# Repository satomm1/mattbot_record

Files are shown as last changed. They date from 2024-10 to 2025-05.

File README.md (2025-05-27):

# Streaming Stereo Audio from I2S PCM Microphones to Nvidia Jetson Orin Nano

This repo contains code for streaming stereo audio from I2S PCM microphones to a Nvidia Jetson Orin Nano developer kit. In my case, I use a InvenSense ICS-43434 MEMS microphone. To convert the 24 bit PCM data output from the microphone to a form readable by the Jetson audio drivers, I use a PIC32MK0128MCA048T-I/Y8X microcontroller to convert the data to 32 bit and the correct endianness. 

Custom PCBs were designed to facilitate the MEMS microphones, PIC32, and connection to the Jetson. These PCBs were designed with KICAD and the designs (and KICAD files) are located in the `./pcb` directory. To order your own PCBs, the necessary gerber files are located in a `./pcb/*/gerber` directory. A BOM for each of the pcbs is also located in the directory (with part numbers for ordering from DigiKey).

The firmware for the PIC32 is located in the `./firmware` directory. This code should be loaded onto the PIC32 and supports sampling rates up to 44,100 Hz.

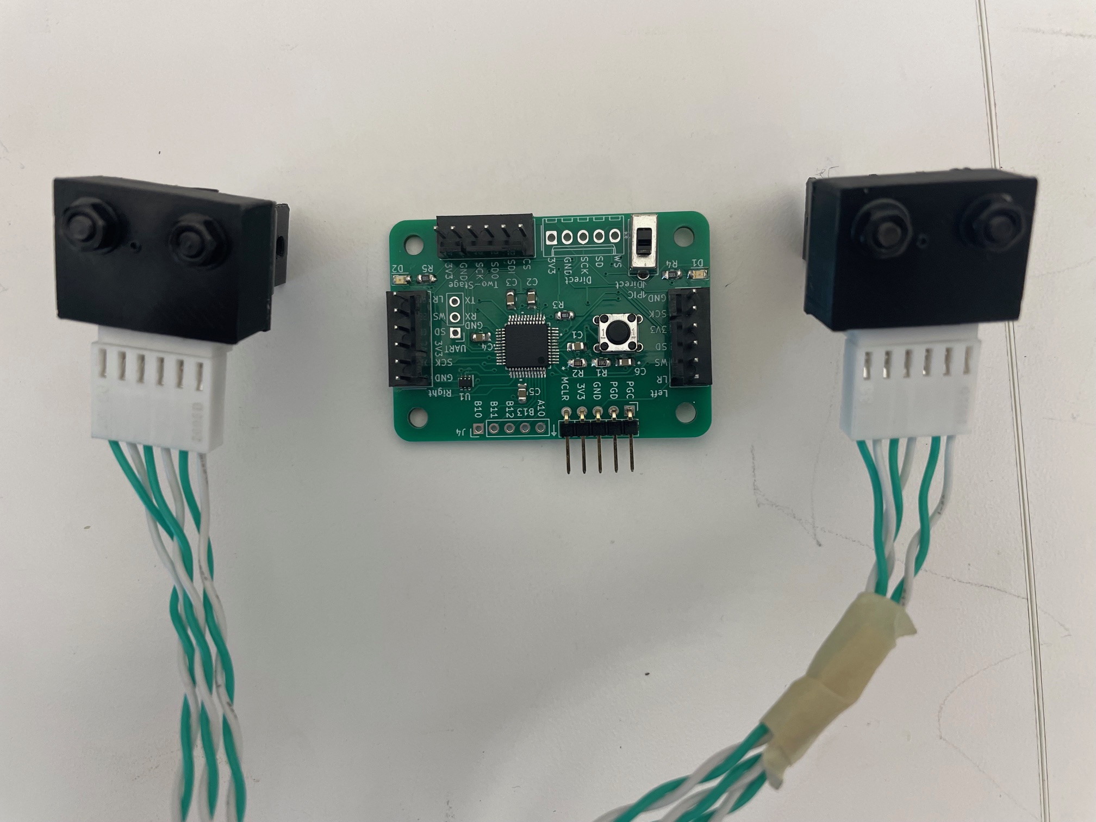
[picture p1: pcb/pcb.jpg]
PCB Design


I include STL/Solidworks files for mounts for the microphones in the `./mounts` directory. These can be 3D printed. For a gasket, you can use a foam double sided tape found at a hardware store. For an acoustically transparent fabric to protect the port, I used muslin which can be found at a fabric store.

To enable the I2S on the Jetson, enable the I2S functionality via:
```
sudo python3 /opt/nvidia/jetson-io/jetson-io.py
```
As a simple test to see if the audio is working, you can use these commands to save a recording to `output.wav`:
```
amixer -c APE cset name="ADMAIF2 Mux" I2S2
arecord -D hw:APE,1 -r 16000 -c 2 -f S32_LE output.wav
```
Note, you will need to run the `amixer` command regardless before I2S audio will be read by the Jetson. It may also be necessary to run `python3 ./scripts/channels.py` to determine which audio device to use for the above example. If you find you need to change from `hw:APE,1` to something else, you will need to modify the other python files as well.

To use the I2S on the Nvidia Jetson with Python, you need to make sure you have installed the following packages:
```
pip install pyalsaaudio
sudo apt-get install libasound2-dev
sudo apt-get install alsa-utils
```
To test the python audio, run:
```
python3 ./scripts/record.py
```
which will save a short 5 second recording to `./scripts/output.wav`. To see the sound in frequency domain, you can run `./scripts/analyze_wav.py`.

We use a wakeword to determine when to start listening. The opensource [openWakeWord](https://github.com/dscripka/openWakeWord) is used to identify "Hey Robot," but the openWakeWord repo describes how to easily create your own wakeword. We also use the opensource [Silero voice activity detector](https://github.com/snakers4/silero-vad) to identify when speech has ended. Speech which is recorded is transcribed using [Whisper](https://github.com/openai/whisper). Recently, the transcription has been changed to [Faster Whisper](https://github.com/SYSTRAN/faster-whisper), which uses less computational resources. These features require the installation of additional dependencies:
```
pip install openwakeword
pip install silero-vad
pip install -U openai-whisper
pip install faster-whisper
```

Note: As of 12/7/2024, there is issues with the python package tokenizer version 0.21.0 for faster-whisper. I recommend installing an earlier version.

You will also need to download model files for openWakeWord. You can do this with `openwakeword.utils.download_models()` in python, or you can just run `./scripts/wakeword.py` which will also download the necessary model files.

Putting all this together, we create a function which:
1) Initializes the I2S interface on the Jetson.
2) Records audio using the I2S interface.
3) Detects the wakeword using openWakeWord.
4) Records speech until silence is detected using Silero VAD.
5) Saves the recorded audio to a file.
6) Transcribes the audio.
7) (optional) Sends the transcription to an LLM for a response.
Try it out using:
```
python3 ./scripts/get_audio_wakeword_speech_detection.py
```
This repo is set up as a ROS package compatible with ROS Noetic.

## Launching the Microphones
The relevant launch file is `audio_with_speech_detection.launch` which can be run with:
```
roslaunch mattbot_record audio_with_speech_detection.launch
```

**Author**: Matthew Sato, Stanford Engineering Informatics Group

**License**: This package is released under an [MIT License](./LICENSE).

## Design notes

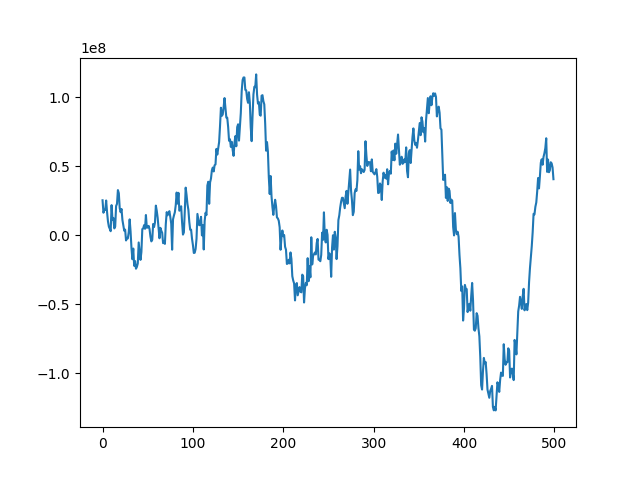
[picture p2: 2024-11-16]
scripts/audio_data.png

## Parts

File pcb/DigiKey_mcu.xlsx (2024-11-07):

References | Value | Mfr | Mfr P/N | Supplier 1 | Supplier 1 P/N | Quantity
C1, C2, C3, C4, C5, C6 | 0.1 uF | Samsung Electro-Mechanics | CL21B104KBCNNNC | DigiKey | 1276-1003-1-ND | 6
R4, R5 | 130R | Stackpole Electronics Inc | RMCF0805FT130R | DigiKey | RMCF0805FT130RCT-ND | 2
R1 | 10k | Stackpole Electronics Inc | RMCF0805JT10K0 | DigiKey | RMCF0805JT10K0CT-ND | 1
R2 | 1k | Stackpole Electronics Inc | RMCF0805FT1K00 | DigiKey | RMCF0805FT1K00CT-ND | 1
R3 | 100k | Stackpole Electronics Inc | RMCF0805FG100K | DigiKey | RMCF0805FG100KCT-ND | 1
D1, D2 | LED | Würth Elektronik | 150080RS75000 | DigiKey | 732-4984-1-ND | 2
U1 | GSF7002DW | Good-Ark Semiconductor | GSF7002DW | DigiKey | 4786-GSF7002DWCT-ND | 1
SW1 | B3F-1020 | Omron Electronics Inc-EMC Div | B3F-1020 | DigiKey | SW402-ND | 1
SW2 | SW_SPDT | C&K | OS102011MS2QN1 | DigiKey | CKN9565-ND | 1
IC1 | PIC32MK0128MCA048-I_Y8X | Microchip Technology | PIC32MK0128MCA048T-I/Y8X | DigiKey | 150-PIC32MK0128MCA048T-I/Y8XCT-ND | 1
J2, J3, J5 | Conn_01x06 | Molex | 1718560006 | DigiKey | WM10156-ND | 3
J6 | Conn_01x05 | Molex | 1718560005 | DigiKey | WM10183-ND | 1
J8 | Conn-Femalex6 | Molex | 22012067 | DigiKey | WM2015-ND | 3
J9 | Conn-Femalex5 | Molex | 22012057 | DigiKey | WM2014-ND | 1
J10 | Conn-Crimp | Molex | 8510108 | DigiKey | WM19393CT-ND | 8

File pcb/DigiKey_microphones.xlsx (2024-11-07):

References | Value | Mfr | Mfr P/N | Supplier 1 | Supplier 1 P/N | Quantity
C1 | 0.1 uF | Samsung Electro-Mechanics | CL21B104KBCNNNC | DigiKey | 1276-1003-1-ND | 1
MK1 | ICS-43434 | TDK InvenSense | ICS-43434 | DigiKey | 1428-1066-1-ND | 1
J1 | Conn2MCU | Molex | 22053061 | DigiKey | WM4304-ND | 1
J2 | Conn2MCU-Female | Molex | 22012067 | DigiKey | WM2015-ND | 1
J3 | Conn2MCU-Crimp | Molex | 8510108 | DigiKey | WM19393CT-ND | 2

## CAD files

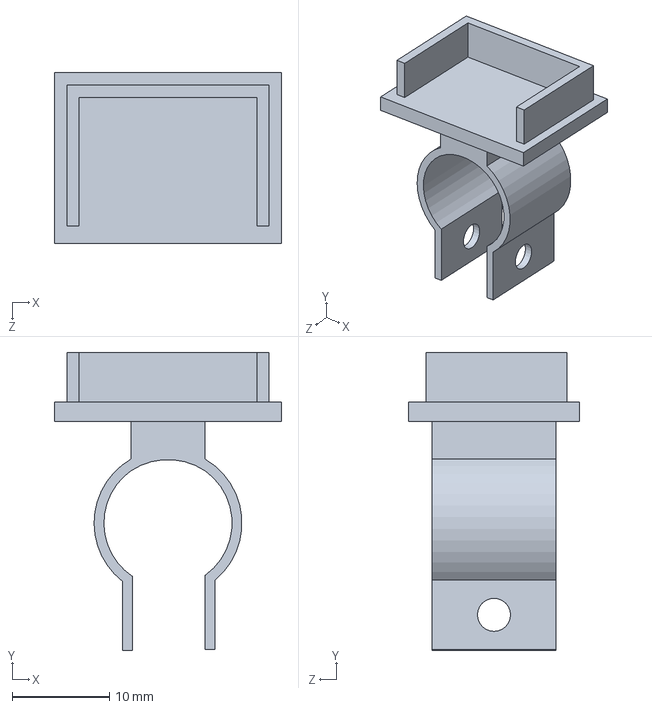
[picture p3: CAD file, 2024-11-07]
mounts/casing_back.SLDPRT
23.3 x 30.6 x 17.5 mm

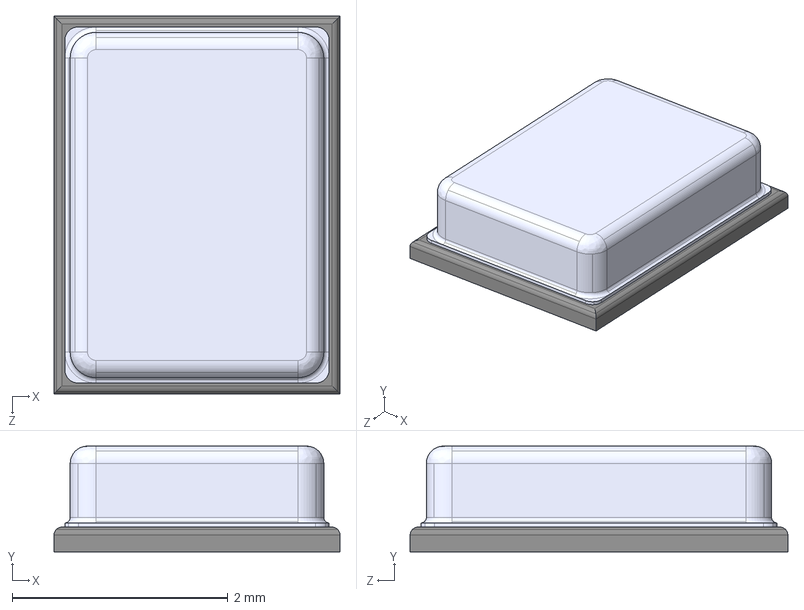
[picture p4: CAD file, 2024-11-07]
pcb/microphone/3dmodels/ICS-43434.step
2.65 x 0.98 x 3.50 mm

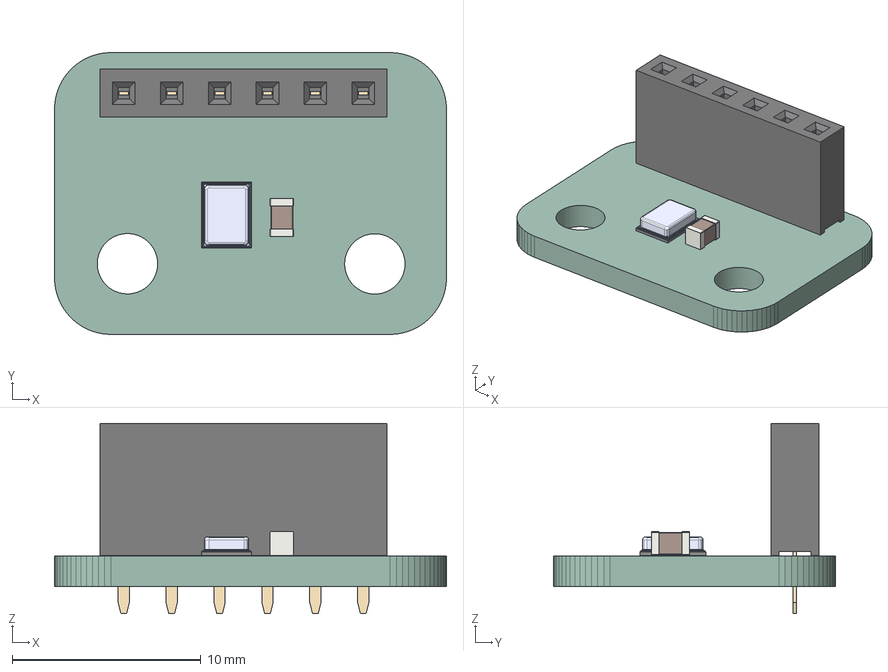
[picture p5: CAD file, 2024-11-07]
pcb/microphone/microphone.step
20.8 x 15.0 x 10.1 mm
microphone PCB

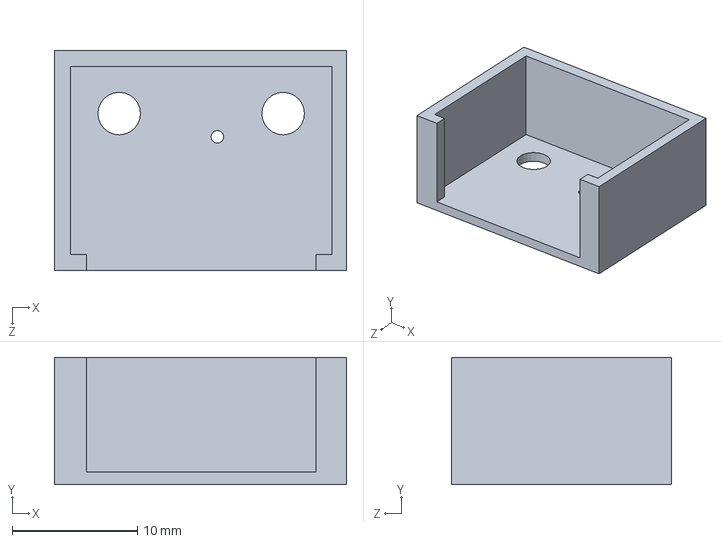
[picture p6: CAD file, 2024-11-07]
mounts/casing.SLDPRT
23.3 x 10.2 x 17.5 mm

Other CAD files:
mounts/casing.STL
mounts/casing_back.STL

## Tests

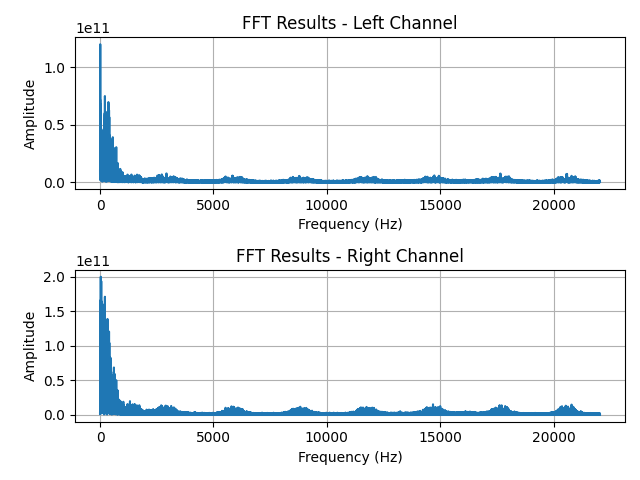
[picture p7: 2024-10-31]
scripts/fft_result.png

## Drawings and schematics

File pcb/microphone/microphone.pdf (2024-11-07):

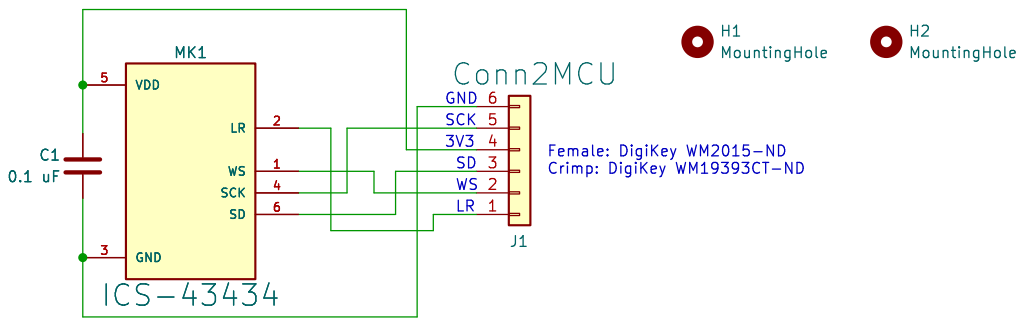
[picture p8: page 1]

LR 1

Id: 1/1 Title: Test sheet File: microphone.kicad_sch Sheet: / satomm@stanford.edu

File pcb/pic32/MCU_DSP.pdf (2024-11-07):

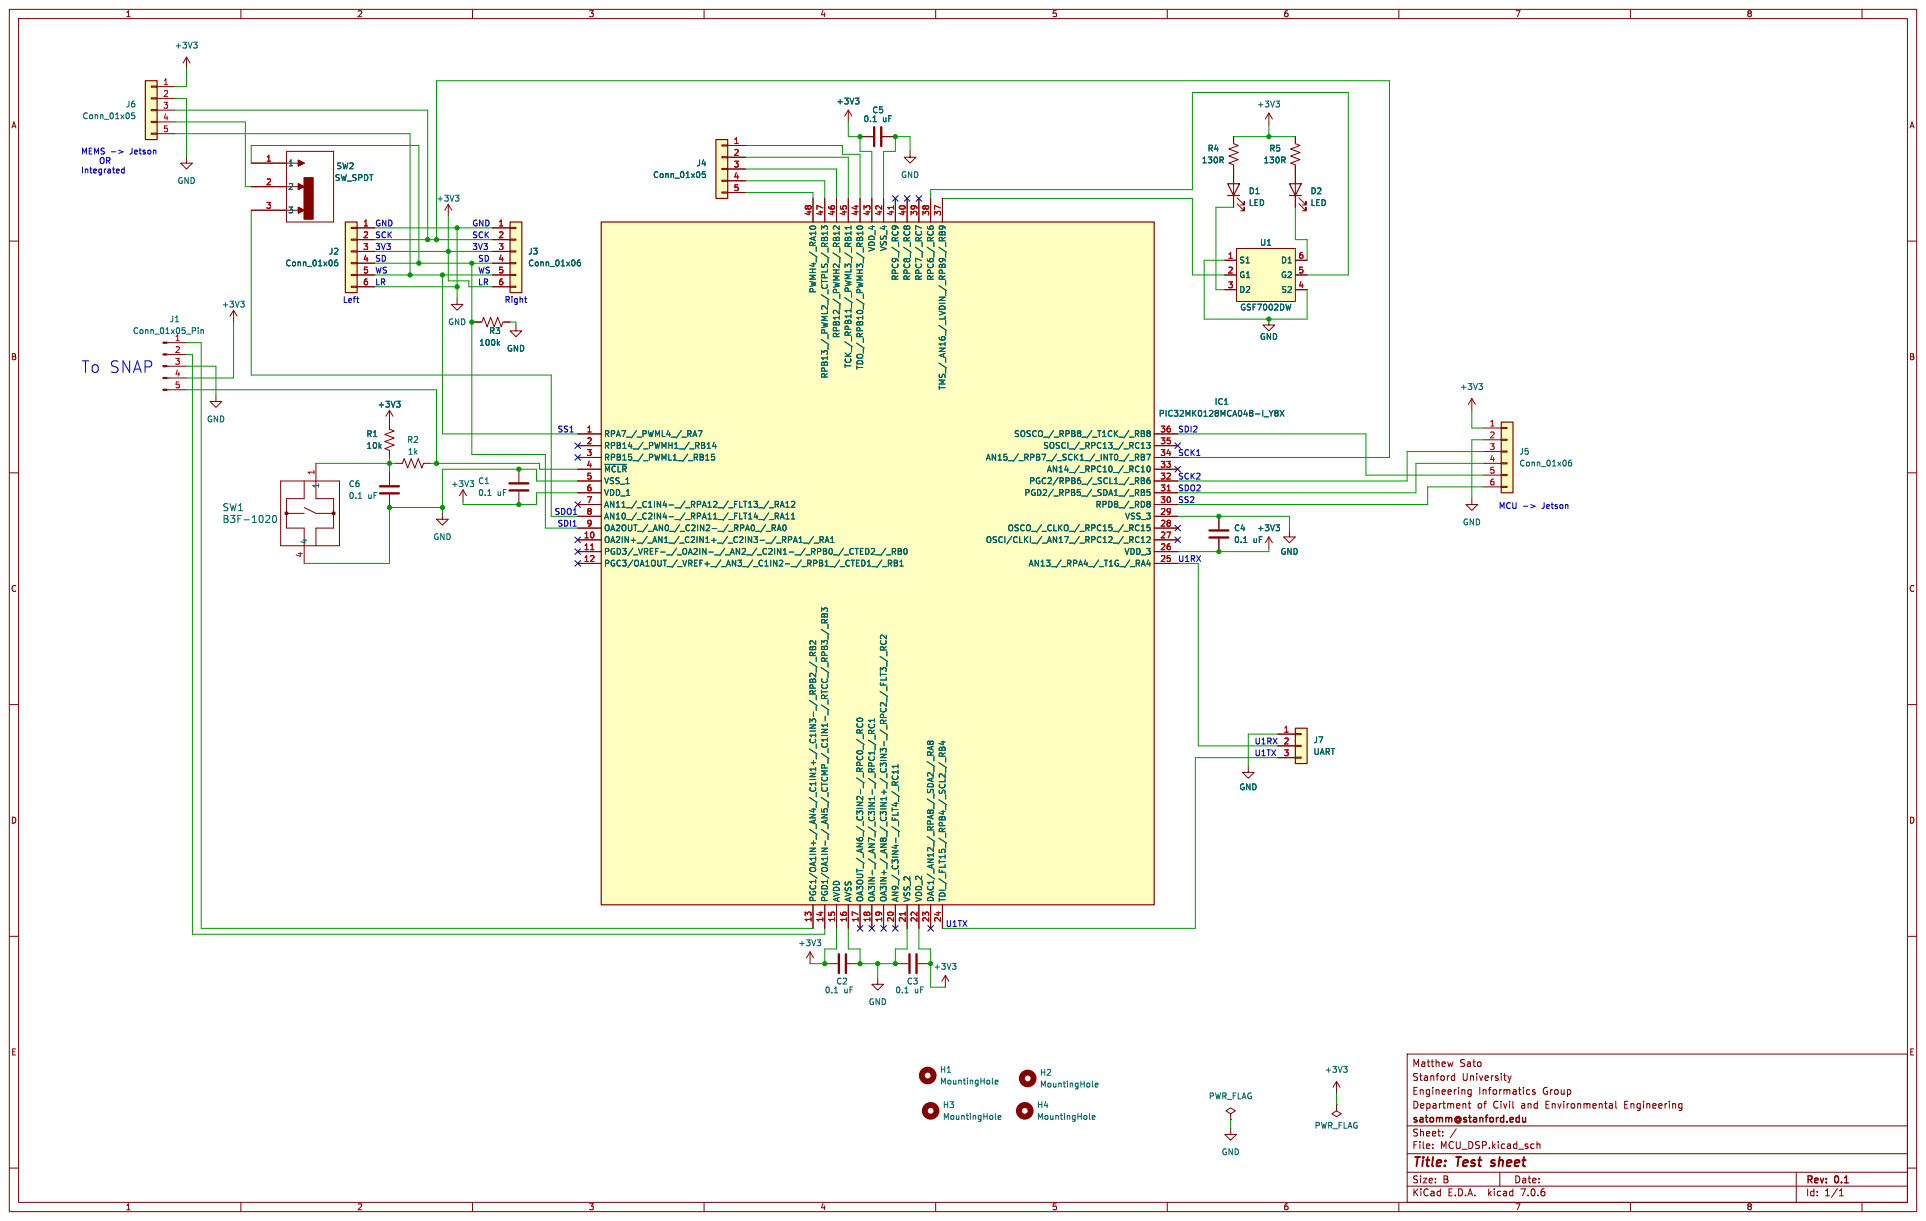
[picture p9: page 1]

Id: 1/1 Title: Test sheet File: MCU_DSP.kicad_sch Sheet: / satomm@stanford.edu

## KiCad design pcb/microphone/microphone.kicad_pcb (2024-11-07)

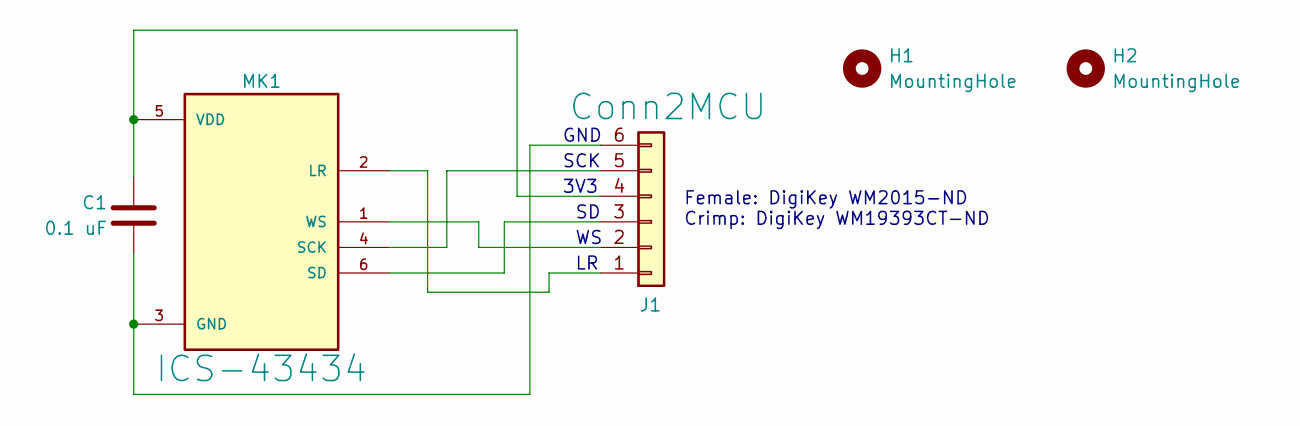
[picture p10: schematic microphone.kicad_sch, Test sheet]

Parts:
C1: 0.1 uF; C_0805_2012Metric_Pad1.18x1.45mm_HandSolder; Mfr P/N CL21B104KBCNNNC
H1, H2: MountingHole; MountingHole_3.2mm_M3
J1: Conn2MCU; CONN_22-05-3061_MOL; Mfr P/N 0022053061
MK1: ICS-43434; MIC_ICS-43434; Mfr P/N ICS-43434

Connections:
unnamed: J1.1, MK1.2 (LR)
unnamed: J1.2, MK1.1 (WS)
unnamed: J1.3, MK1.6 (SD)
unnamed: C1.1, J1.4, MK1.5 (VDD)
unnamed: J1.5, MK1.4 (SCK)
unnamed: C1.2, J1.6, MK1.3 (GND)

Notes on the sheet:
GND
Female: DigiKey WM2015-ND Crimp: DigiKey WM19393CT-ND
3V3
SCK

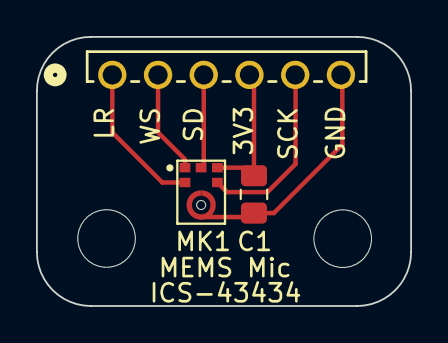
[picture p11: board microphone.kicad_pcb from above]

Board: 2 copper layers, 20.8 x 15.0 mm, 5 parts (0 on the bottom side), 6 nets.

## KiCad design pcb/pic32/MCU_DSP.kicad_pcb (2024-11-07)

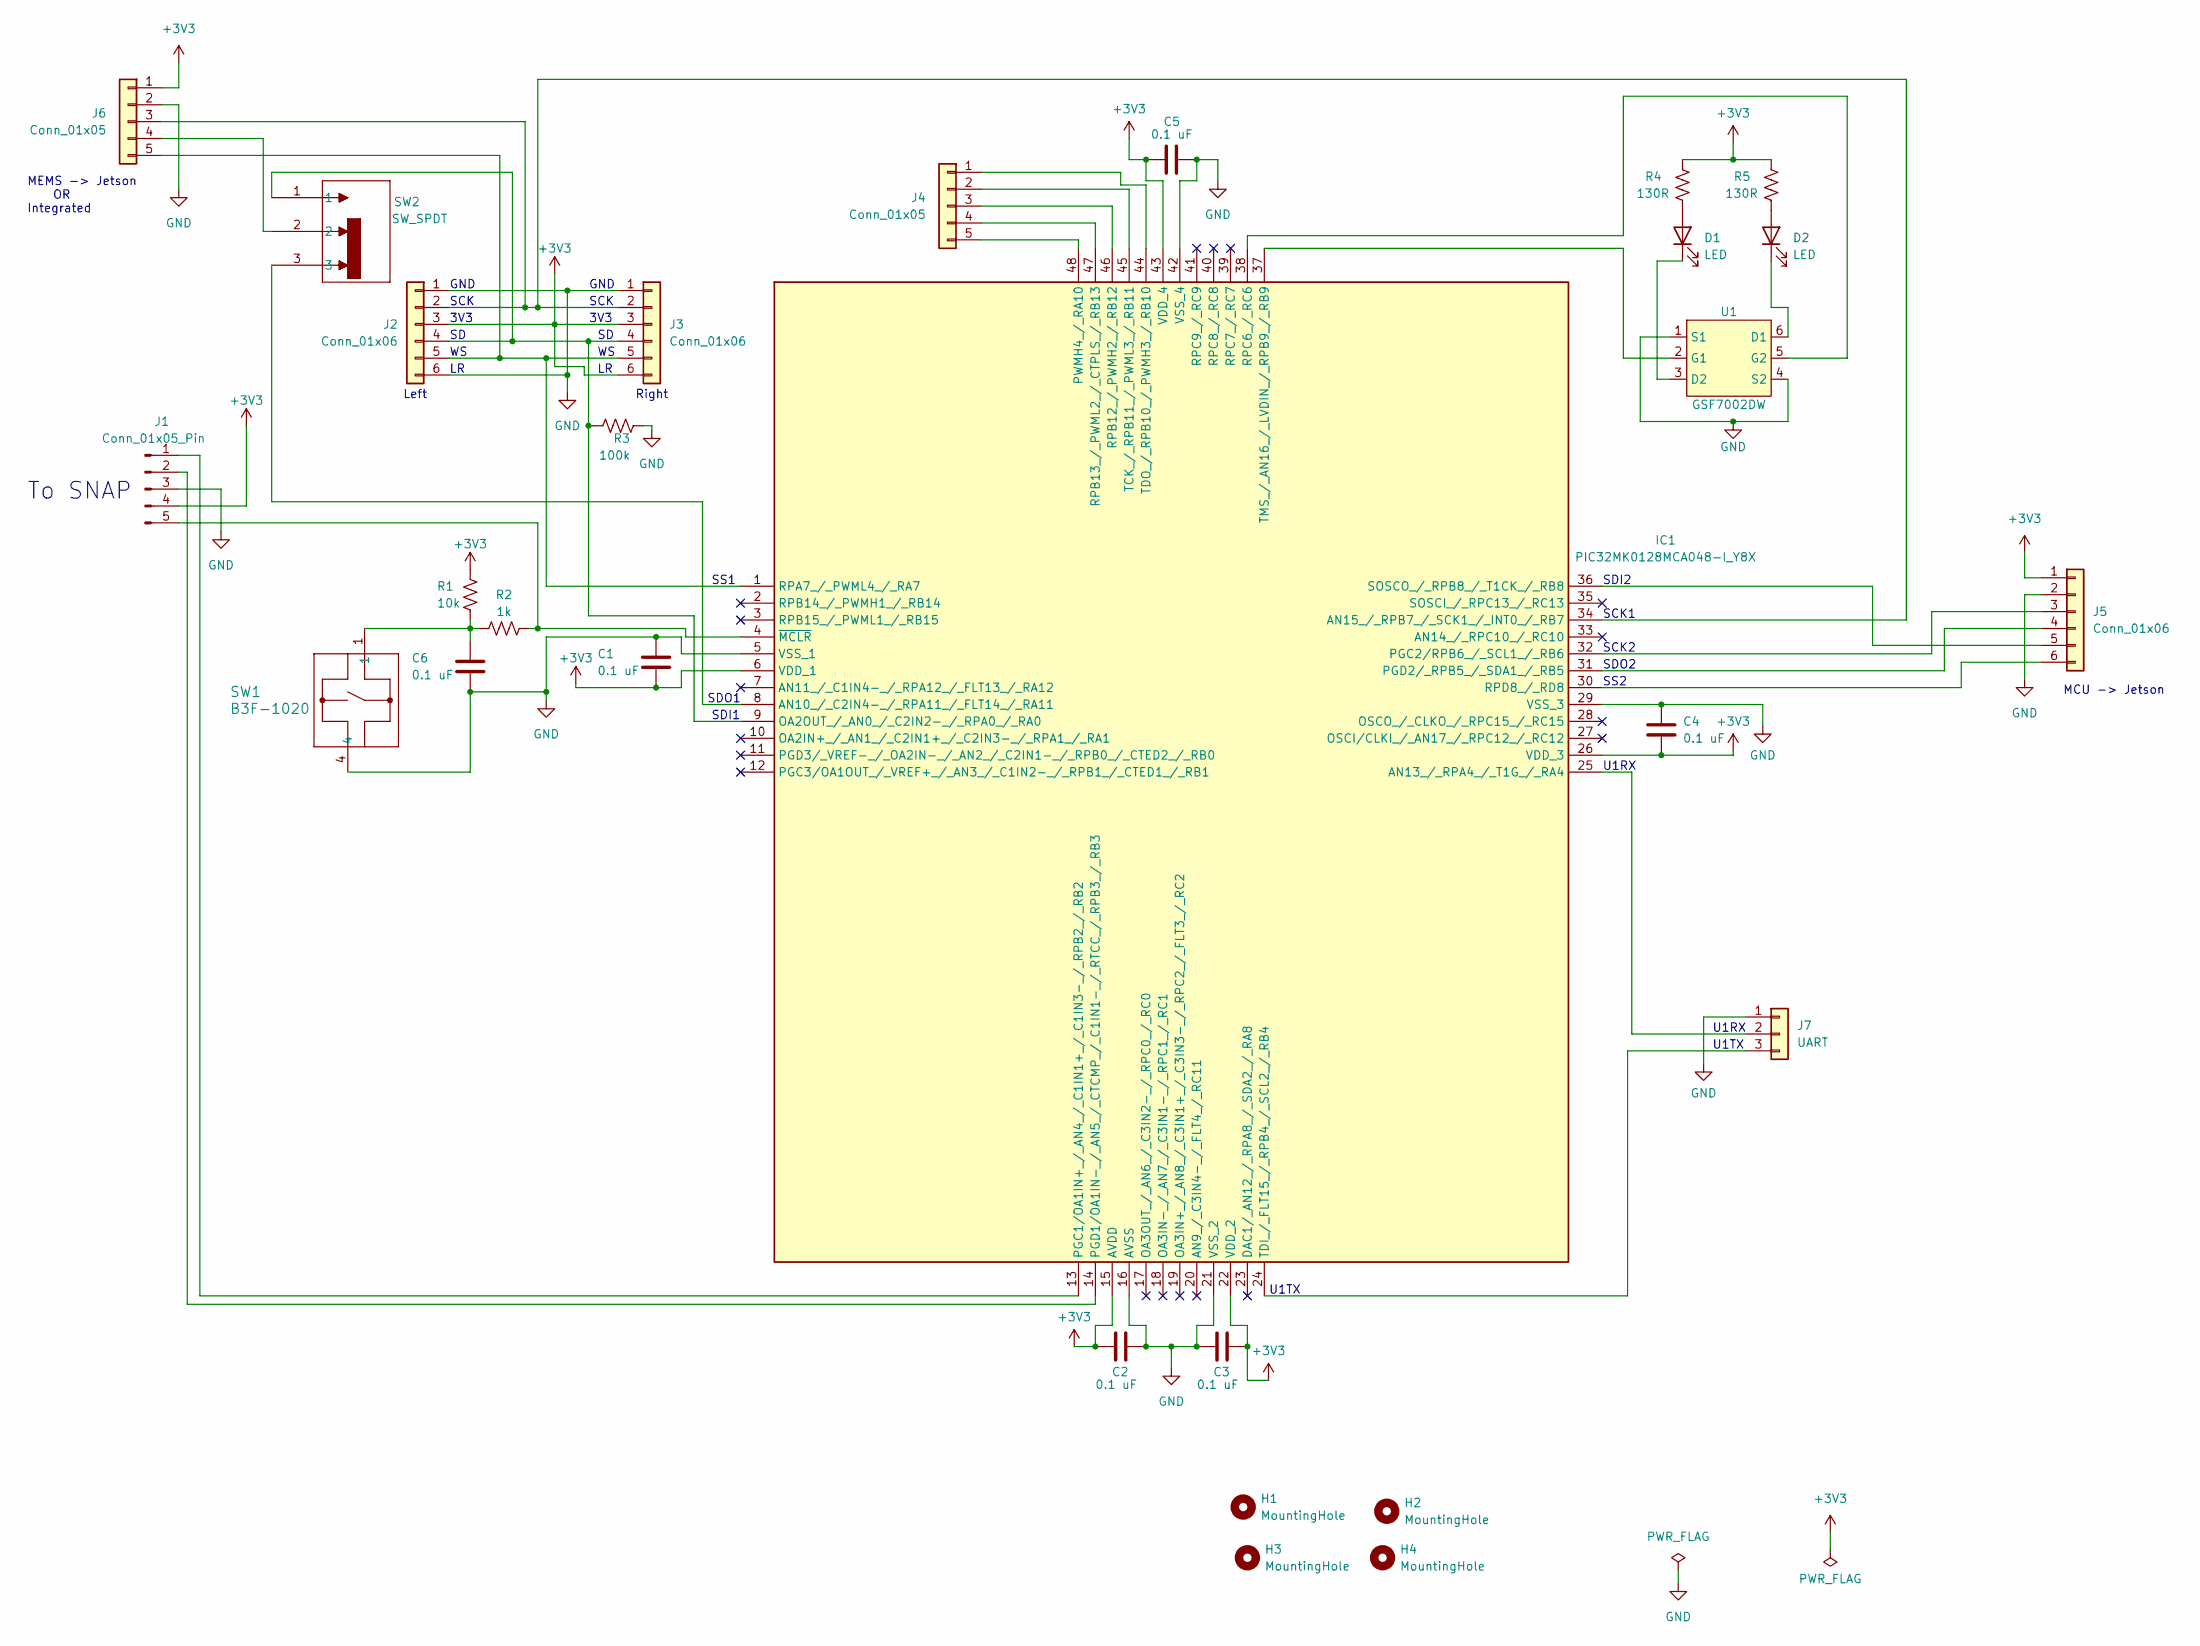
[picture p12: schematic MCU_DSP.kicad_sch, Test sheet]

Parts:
C1, C2, C3, C4, C5, C6: 0.1 uF; C_0805_2012Metric_Pad1.18x1.45mm_HandSolder; Mfr P/N CL21B104KBCNNNC
D1, D2: LED; LED_0805_2012Metric_Pad1.15x1.40mm_HandSolder; Mfr P/N 150080RS75000
H1, H2, H3, H4: MountingHole; MountingHole_3.2mm_M3
IC1: PIC32MK0128MCA048-I_Y8X; TQFP48_Y8X_MCH-M; Mfr P/N PIC32MK0128MCA048T-I/Y8X
J1: Conn_01x05_Pin; PinHeader_1x05_P2.54mm_Horizontal; Mfr P/N 10129379-910002BLF
J2, J3, J5: Conn_01x06; Molex_KK-254_AE-6410-06A_1x06_P2.54mm_Vertical; Mfr P/N 1718560006
J4: Conn_01x05; PinHeader_1x05_P2.54mm_Vertical
J6: Conn_01x05; Molex_KK-254_AE-6410-05A_1x05_P2.54mm_Vertical; Mfr P/N 1718560005
J7: UART; PinHeader_1x03_P2.54mm_Vertical
R1: 10k; R_0805_2012Metric_Pad1.20x1.40mm_HandSolder; Mfr P/N RMCF0805JT10K0
R2: 1k; R_0805_2012Metric_Pad1.20x1.40mm_HandSolder; Mfr P/N RMCF0805FT1K00
R3: 100k; R_0805_2012Metric_Pad1.20x1.40mm_HandSolder; Mfr P/N RMCF0805FG100K
R4, R5: 130R; R_0805_2012Metric_Pad1.20x1.40mm_HandSolder; Mfr P/N RMCF0805FT130R
SW1: B3F-1020; SW_B3F-1000_OMR; Mfr P/N B3F-1020
SW2: SW_SPDT; SPDT_OS102011_CNK; Mfr P/N OS102011MS2QN1
U1: GSF7002DW; SOT-363_SC-70-6; Mfr P/N GSF7002DW

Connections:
+3V3: C1.2, C2.1, C3.2, C4.2, C5.2, IC1.6 (VDD_1), IC1.15 (AVDD), IC1.22 (VDD_2), IC1.26 (VDD_3), IC1.43 (VDD_4), J1.4, J2.3, J3.3, J3.6, J5.1, J6.1, R1.1, R4.1, R5.1
GND: C1.1, C2.2, C3.1, C4.1, C5.1, C6.2, IC1.5 (VSS_1), IC1.16 (AVSS), IC1.21 (VSS_2), IC1.29 (VSS_3), IC1.42 (VSS_4), J1.3, J2.1, J2.6, J3.1, J5.2, J6.2, J7.1, R3.2, SW1.4, U1.1 (S1), U1.4 (S2)
unnamed: C6.1, R1.2, R2.1, SW1.1
unnamed: D1.2 (A), R4.2
unnamed: D1.1 (K), U1.3 (D2)
unnamed: D2.2 (A), R5.2
unnamed: D2.1 (K), U1.6 (D1)
unnamed: IC1.8 (AN10_/_C2IN4-_/_RPA11_/_FLT14_/_RA11), SW2.3
unnamed: IC1.25 (AN13_/_RPA4_/_T1G_/_RA4), J7.2
unnamed: IC1.34 (AN15_/_RPB7_/_SCK1_/_INT0_/_RB7), J2.2, J3.2, J6.3
unnamed: IC1.9 (OA2OUT_/_AN0_/_C2IN2-_/_RPA0_/_RA0), J2.4, J3.4, R3.1, SW2.1
unnamed: IC1.13 (PGC1/OA1IN+_/_AN4_/_C1IN1+_/_C1IN3-_/_R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), J1.1
unnamed: IC1.32 (PGC2/RPB6_/_SCL1_/_RB6), J5.3
unnamed: IC1.14 (PGD1/OA1IN-_/_AN5_/_CTCMP_/_C1IN1-_/_RT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), J1.2
unnamed: IC1.31 (PGD2/_RPB5_/_SDA1_/_RB5), J5.4
unnamed: IC1.48 (PWMH4_/_RA10), J4.5
unnamed: IC1.1 (RPA7_/_PWML4_/_RA7), J2.5, J3.5, J6.5
unnamed: IC1.46 (RPB12_/_PWMH2_/_RB12), J4.3
unnamed: IC1.47 (RPB13_/_PWML2_/_CTPLS_/_RB13), J4.4
unnamed: IC1.38 (RPC6_/_RC6), U1.5 (G2)
unnamed: IC1.30 (RPD8_/_RD8), J5.6
unnamed: IC1.36 (SOSCO_/_RPB8_/_T1CK_/_RB8), J5.5
unnamed: IC1.45 (TCK_/_RPB11_/_PWML3_/_RB11), J4.2
unnamed: IC1.24 (TDI_/_FLT15_/_RPB4_/_SCL2_/_RB4), J7.3
unnamed: IC1.44 (TDO_/_RPB10_/_PWMH3_/_RB10), J4.1
unnamed: IC1.37 (TMS_/_AN16_/_LVDIN_/_RPB9_/_RB9), U1.2 (G1)
unnamed: IC1.4 (~MCLR), J1.5, R2.2
unnamed: J6.4, SW2.2

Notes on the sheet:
SCK
3V3
U1TX
SS2
GND
MCU -> Jetson
SDO2
SDI2
U1RX
SCK2
SS1
Left
MEMS -> Jetson OR Integrated
To SNAP
SDO1
Right
SDI1
SCK1

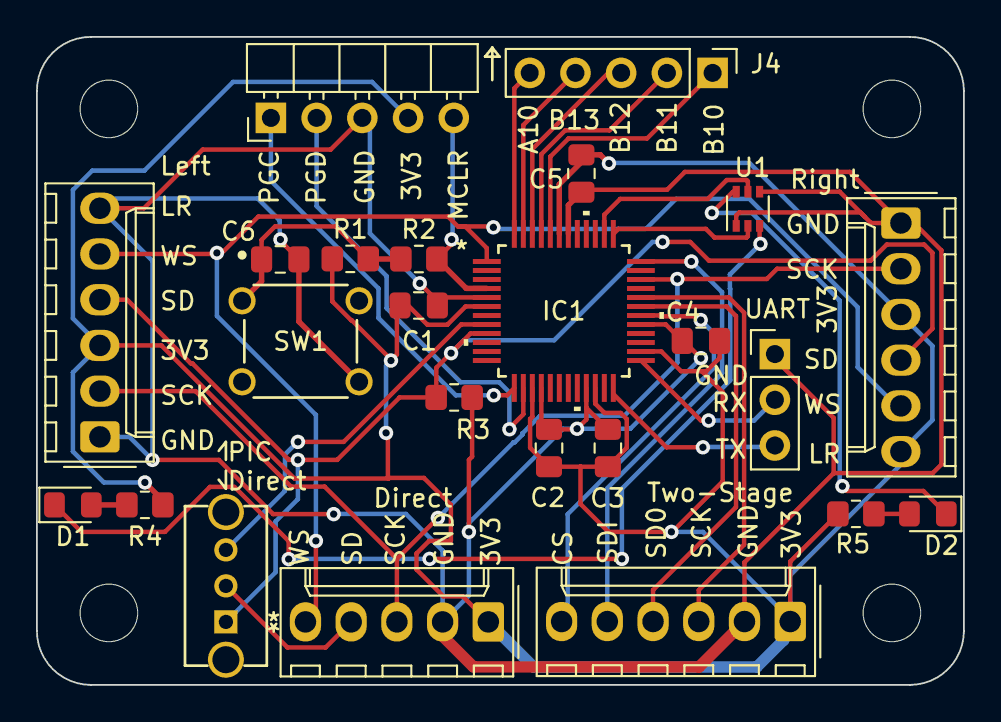
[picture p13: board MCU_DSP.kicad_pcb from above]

Board: 2 copper layers, 51.5 x 36.0 mm, 28 parts (0 on the bottom side), 28 nets.

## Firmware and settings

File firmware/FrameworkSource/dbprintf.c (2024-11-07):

//#define TEST
/****************************************************************************
  Module
    dbprintf.c

  Description
    This is a module implementing  a printf() like function that has been
    stripped down to reduce its code size & memory usage.  The only format
    specifiers  recognized are : %d, %x, %u, %c, %s . It can not print
    floats or longs. If it is called with a format specifier other than
    those recognized, it will print BAD. Any values after that are garbage.
    Floats must be explicitly  cast to int before printing.

  Notes
    The maximum line length from a single call to DB_printf() is LINE_LEN
    characters. This is the size of an allocated buffer. If you exceed this,
    you will overrun the stack. The length of any number field in the
    resulting line can not be longer than FIELD_LEN.

 History
 When           Who     What/Why
 -------------- ---     --------
 10/06/20 22:53 ram     updated to use the terminal module. Updated variable 
                        names to make MPLAB happy during parsing
 05/15/02 21:40 jec      converted to use SC1 for use in me218c project master
 02/23/98 21:40 jec      made cl & ch explicitly signed in the test program
                         this is because introl defaults to unsigned chars
 02/22/98 23:32 jec      removed itoa, we only really need uitoa
 02/15/98 10:34 jec      Began Coding
****************************************************************************/
/*----------------------------- Include Files -----------------------------*/
#include <stdio.h>
#include <stdarg.h>
#include "terminal.h"
#include "dbprintf.h"

/*----------------------------- Module Defines ----------------------------*/
// increased line length because the assert() lines can get long)
#define LINE_LEN    120
// increased FIELD_LEN to accommodate 32 bit values for ints
#define FIELD_LEN   11

#define CR 0x0d
#define LF 0x0a
/*---------------------------- Module Functions ---------------------------*/
static void uitoa(char **buf, unsigned int i, unsigned int baseNum);

/*---------------------------- Module Variables ---------------------------*/

/*------------------------------ Module Code ------------------------------*/
/****************************************************************************
 Function
    DB_printf

 Parameters
    a char * format string, followed by a variable number of arguments

 Returns
    None.

 Description
    a printf() like function that has been
    stripped down to reduce its code size & memory usage.  The only format
    specifiers  recognized are : %d, %x, %u, %c, %s . 
 Notes
    It can not print floats or longs. 
    If it is called with a format specifier other than those recognized, 
    it will print BAD. Any values after that are garbage.
    Floats must be explicitly  cast to int before printing.
 Author
    J. Edward Carryer, 05/15/02 21:51
****************************************************************************/
void DB_printf(const char *Format, ...)
{
  va_list Arguments;
  char *pBuffer;
  char *pString;
  int   i;
	unsigned int u;
  char  LineBuffer[LINE_LEN+1];

  va_start(Arguments,Format);
  pBuffer = LineBuffer;
  *pBuffer = 0;                 /* make sure that Line starts out NULL term */
  while (*Format)               /* step through the format string */
  {    
    if (*Format != '%')            /* if not a format specifier */
    {      
      *pBuffer++ = *Format++;  /* simply copy to the output buffer */
    }else
    {
       switch (*++Format)         /* otherwise see what kind of format spec */
       {
          case 'd':               /* %d, decimal signed number */
             i = va_arg(Arguments,int);
             if (i < 0)
             {
                *pBuffer++ = '-'; /* add '-' to the buffer for neg. numbers */
                i = -1*i;         /* and continue with the positive version */
             }
             uitoa(&pBuffer, (unsigned int)i, 10);
             break;
          case 'x':               /* %x, hexadecimal unsigned number */
             u = va_arg(Arguments,unsigned int);
//               *pBuffer++ = '0'; removed to allow cleaner printing of longs
//               *pBuffer++ = 'x';
             uitoa(&pBuffer, u, 16);
             break;
          case 'u':               /* %u, decimal unsigned number */
             u = va_arg(Arguments,unsigned int);
             uitoa(&pBuffer, u, 10);
             break;
          case 'c':               /* %c, a single character */
             *pBuffer++ = (char) va_arg(Arguments,unsigned int);
             break;
          case 's':               /* %s, a string of characters */
             pString = va_arg(Arguments,char *);
             if (!pString)
                pString = "(null)";
             while (*pString)
                *pBuffer++ = *pString++;
             break;
          case '%':               /* quoted % */
             *pBuffer++ = '%';
              break;
          default:                /* anything else is a bad spec. */
              *pBuffer++ = 'B';
              *pBuffer++ = 'A';
              *pBuffer++ = 'D';
              break;
       }
       Format++;
    }
  }
  *pBuffer = 0;                     /* null terminate the output string */

/* now, spit the built up line out 1 character at a time */
   for (pBuffer = LineBuffer; *pBuffer != 0; pBuffer++)
   {
      if (*pBuffer != '\n')
      {   
        putchar(*pBuffer);
      }else
      {
         putchar(CR);
         putchar(LF);
      }
   }
   return;
}
/* integer to ascii conversion for unsigned numbers  */
static void uitoa(char **LineBuffer, unsigned int i, unsigned int baseNum)
{
  char *s;
  uint8_t remainder;
  char FieldBuf[FIELD_LEN + 1];

  FieldBuf[FIELD_LEN] = 0;      /*start by NULL terminating the local buffer */
  
  // we treat a value of 0 as a special case, since it would break the
  // general algorithm
  if (i == 0)
  {
    (*LineBuffer)[0] = '0'; // just copy the '0' to the return buffer
    ++(*LineBuffer);        // and advance the pointer past the '0'
    return;
  }
  // we will fill the FieldBuf from the LS position
  s = &FieldBuf[FIELD_LEN];
  while (i)
  {
    remainder = i % baseNum;
    *--s = "0123456789abcdef"[remainder];
    i /= baseNum;
  }
  while (*s)                    /* copy local buffer into passed buffer */
  {
    (*LineBuffer)[0] = *s++;
    ++(*LineBuffer);
  }
}


#ifdef TEST
#define LONGTEST
#include <xc.h>
#include <limits.h>

#define UINT_MIN 0
#define UCHAR_MIN 0

void main(void)
{
#ifdef LONGTEST
  unsigned char ucl=UCHAR_MIN;
  unsigned char uch=UCHAR_MAX;
  unsigned int  uil=UINT_MIN;
  unsigned int  uih=UINT_MAX;
  int   il = INT_MIN;
  int   ih = INT_MAX;
  signed char  cl = SCHAR_MIN;
  signed char  ch = SCHAR_MAX;
  char  c='A';
  char  String[]="Hello World\n";
  float Floater = 1.23;
  unsigned long LongOne = 123456789;

  Terminal_HWInit();
  DB_printf("\nBeginning DB_printf() test compiled at %s on %s\n\n", __TIME__, __DATE__);

   DB_printf("Printing an unsigned char UCHAR_MIN, Decimal mode(%%u): %u, Hex mode: %x\n\n",ucl, ucl);

   DB_printf("Printing an unsigned char UCHAR_MAX, Decimal mode(%%u): %u, Hex mode: %x\n\n",uch, uch);

   DB_printf("Printing an unsigned int UINT_MIN, Decimal mode(%%u): %u, Hex mode: %x\n\n",uil,uil);

   DB_printf("Printing an unsigned int UINT_MAX, Decimal mode(%%u): %u\n",uih);
   DB_printf("Printing an unsigned int UIINT_MAX, Hex mode: %x\n\n",uih);

   DB_printf("Printing an signed char SCHAR_MIN, Decimal mode(%%d): %d\n",cl);
   DB_printf("Printing an signed char SCHAR_MAX, Decimal mode(%%d):  %d\n\n",ch);
   
   DB_printf("Printing an signed int INT_MIN, Decimal mode(%%d): %d\n",il);
   DB_printf("Printing an signed int INT_MAX, Decimal mode(%%d):  %d\n\n",ih);

   DB_printf("Printing a char as a single character: %c\n", c);
   DB_printf("Printing a string w/ embedded NL: %s\n\n", String);

   DB_printf("Attempting to print a long: %l\n",LongOne);
   DB_printf("Attempting to print a float: %f\n",Floater);
//   DB_printf("A way to print a long value: %x%x\n", HIWORD(LongOne),LOWORD(LongOne));

#else
   Terminal_HWInit();
  DB_printf("\nBeginning DB_printf() test:\n");
  DB_printf( "compiled at %s on %s\n", __TIME__, __DATE__);
   DB_printf("Hello World!\n");
#endif  //LONGTEST

  while(1) //hang out in this loop forever, moving bytes to UART until finished
  {
    Terminal_MoveBuffer2UART(); // move bytes from circ buffer to UART
  }
}
#endif // TEST

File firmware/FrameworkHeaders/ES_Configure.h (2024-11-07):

/****************************************************************************
 Module
     ES_Configure.h
 Description
     This file contains macro definitions that are edited by the user to
     adapt the Events and Services framework to a particular application.
 Notes

 History
 When           Who     What/Why
 -------------- ---     --------
 12/19/16 20:19  jec     removed EVENT_CHECK_HEADER definition. This goes with
                         the V2.3 move to a single wrapper for event checking
                         headers
  10/11/15 18:00 jec     added new event type ES_SHORT_TIMEOUT
  10/21/13 20:54 jec     lots of added entries to bring the number of timers
                         and services up to 16 each
 08/06/13 14:10 jec      removed PostKeyFunc stuff since we are moving that
                         functionality out of the framework and putting it
                         explicitly into the event checking functions
 01/15/12 10:03 jec      started coding
*****************************************************************************/

#ifndef ES_CONFIGURE_H
#define ES_CONFIGURE_H

/****************************************************************************/
// The maximum number of services sets an upper bound on the number of
// services that the framework will handle. Reasonable values are 8 and 16
// corresponding to an 8-bit(uint8_t) and 16-bit(uint16_t) Ready variable size
#define MAX_NUM_SERVICES 16

/****************************************************************************/
// This macro determines that nuber of services that are *actually* used in
// a particular application. It will vary in value from 1 to MAX_NUM_SERVICES
#define NUM_SERVICES 3

/****************************************************************************/
// These are the definitions for Service 0, the lowest priority service.
// Every Events and Services application must have a Service 0. Further
// services are added in numeric sequence (1,2,3,...) with increasing
// priorities
// the header file with the public function prototypes
#define SERV_0_HEADER "TestHarnessService0.h"
// the name of the Init function
#define SERV_0_INIT InitTestHarnessService0
// the name of the run function
#define SERV_0_RUN RunTestHarnessService0
// How big should this services Queue be?
#define SERV_0_QUEUE_SIZE 5

/****************************************************************************/
// The following sections are used to define the parameters for each of the
// services. You only need to fill out as many as the number of services
// defined by NUM_SERVICES
/****************************************************************************/
// These are the definitions for Service 1
#if NUM_SERVICES > 1
// the header file with the public function prototypes
#define SERV_1_HEADER "LedFSM.h"
// the name of the Init function
#define SERV_1_INIT InitLedFSM
// the name of the run function
#define SERV_1_RUN RunLedFSM
// How big should this services Queue be?
#define SERV_1_QUEUE_SIZE 3
#endif

/****************************************************************************/
// These are the definitions for Service 2
#if NUM_SERVICES > 2
// the header file with the public function prototypes
#define SERV_2_HEADER "MicrophoneFSM.h"
// the name of the Init function
#define SERV_2_INIT InitMicrophoneFSM
// the name of the run function
#define SERV_2_RUN RunMicrophoneFSM
// How big should this services Queue be?
#define SERV_2_QUEUE_SIZE 3
#endif

/****************************************************************************/
// These are the definitions for Service 3
#if NUM_SERVICES > 3
// the header file with the public function prototypes
#define SERV_3_HEADER "TestHarnessService3.h"
// the name of the Init function
#define SERV_3_INIT InitTestHarnessService3
// the name of the run function
#define SERV_3_RUN RunTestHarnessService3
// How big should this services Queue be?
#define SERV_3_QUEUE_SIZE 3
#endif

/****************************************************************************/
// These are the definitions for Service 4
#if NUM_SERVICES > 4
// the header file with the public function prototypes
#define SERV_4_HEADER "TestHarnessService4.h"
// the name of the Init function
#define SERV_4_INIT InitTestHarnessService4
// the name of the run function
#define SERV_4_RUN RunTestHarnessService4
// How big should this services Queue be?
#define SERV_4_QUEUE_SIZE 3
#endif

/****************************************************************************/
// These are the definitions for Service 5
#if NUM_SERVICES > 5
// the header file with the public function prototypes
#define SERV_5_HEADER "TestHarnessService5.h"
// the name of the Init function
#define SERV_5_INIT InitTestHarnessService5
// the name of the run function
#define SERV_5_RUN RunTestHarnessService5
// How big should this services Queue be?
#define SERV_5_QUEUE_SIZE 3
#endif
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

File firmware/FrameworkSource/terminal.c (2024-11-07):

//#define TEST
/****************************************************************************
 Module
   terminal.c

 Revision
   1.0.1

 Description
  File holds functions for printing and receiving characters to/from the serial
  emulator through a UART-USB bridge interface.
 Notes
  For the PIC32 port, we are using UART 1

 History
 When           Who     What/Why
 -------------- ---     --------
 08/29/20 14:46 ram     first pass
 10/05/20 19:38 ram     starting work on PIC32 port
 ***************************************************************************/

/*----------------------------- Include Files -----------------------------*/

// Hardware
#include <xc.h>
#include <stdio.h>

#include "ES_General.h"
#include "ES_Port.h"
#include "circular_buffer.h"
#include "dbprintf.h"

//this module
#include "terminal.h"
/*----------------------------- Module Defines ----------------------------*/
#define BAUD_CONST 129// 42 // sets up baud rate for 115200
//#define BAUD_CONST 21 // sets up baud rate for 230400

/*---------------------------- Module Functions ---------------------------*/
/* prototypes for private functions for this service.They should be functions
   relevant to the behavior of this service
*/

/*---------------------------- Module Variables ---------------------------*/
static uint8_t xmitBuffer[XMIT_BUFFER_SIZE];
static cbuf_handle_t xmitBufferHandle;

/*------------------------------ Module Code ------------------------------*/
/*******************************************************************************
 * Function: TerminalInit
 * Arguments: None
 * Returns nothing
 * 
 * Created by: R. Merchant
 * Description: Sets up UART1 to serve as the terminal interface. Sets the baud
 * rate and maps the needed pins
 ******************************************************************************/
void Terminal_HWInit(void)
{
//#define USE_RB2_3
#ifdef USE_RB2_3
  // This was the original pin choice, though we changed this for the project
  // Set up RB2 as RX and RB3 as TX
  // clear analog control
  ANSELB &= (BIT3LO & BIT2LO);
  // start with TX high
  LATBbits.LATB3 = 1;
  // set RB3 as output
  TRISBbits.TRISB3 = 0;
  // set RB2 as input
  TRISBbits.TRISB2 = 1;
  // Remap the pins
  RPB3R = 0b0001; // U1TX -> RB3
  U1RXR = 0b0100; // U1RX <- RB2
#else
  // this moves the UART pins to RB6 & RB7, freeing up RB2 & RB3 to be used
  // as analog inputs
  ANSELA &= (BIT4LO);  // clear analog control
  LATBbits.LATB4 = 1;           // start with TX high
  TRISBbits.TRISB4 = 0;         // set RB7 as output
  TRISAbits.TRISA4 = 1;         // set RB6 as input
  RPB4R = 0b0001;               // map U1TX -> RB4
  U1RXR = 0b0010;               // map U1RX <- RA4
#endif  //USE_RB2_3
  
  // disable the UART to be safe
  U1MODEbits.ON = 0;
  // Setup high-speed mode, data = 8 bit, no parity, 1 stop bit
  // Disable: loop-back, autobaud, wake, inversion
  U1MODEbits.BRGH = 1;
  // Diable TX inversion, everything else we don't care about
  U1STA = 0;
  // Set the baud rate based on the constant
  U1BRG = BAUD_CONST;
  
  // redirect printf to UART1 using X32 built in cross over
  __XC_UART = 1; 
  
  // enable the UART module
  U1STAbits.UTXEN = 1; // enable transmit 
  U1STAbits.URXEN = 1; // enable receive
  U1MODEbits.ON = 1; // turn peripheral on
  
  // now initialize the circular buffer for transmitting
  xmitBufferHandle = circular_buf_init( xmitBuffer, ARRAY_SIZE(xmitBuffer) );
  
  return;
}
/*******************************************************************************
 * Function: Terminal_ReadByte
 * Arguments: None
 * Returns byte
 * 
 * Created by: R. Merchant
 * Description: Read the byte from the receive register
 ******************************************************************************/
uint8_t Terminal_ReadByte(void)
{
  // wait for there to be something
  while(!(U1STAbits.URXDA))
  {}
  // if there was an overrun, clear it to reset the unit
  if(U1STAbits.OERR) U1STAbits.OERR = 0;
  // return the content of the receive register
  return U1RXREG;
}
/*******************************************************************************
 * Function: Terminal_Write
 * Arguments: byte to write
 * Returns nothing
 * 
 * Created by: R. Merchant
 * Description: Writes the byte to the transmit register or buffer
 ******************************************************************************/
void Terminal_WriteByte(uint8_t txByte)
{
#ifdef NO_BUFFER
  // wait for the register to empty
  while(U1STAbits.UTXBF)
  {}
  // write the byte to the register
  U1TXREG = txByte;
#else
  circular_buf_put(xmitBufferHandle, txByte);
#endif  
  return;
}
/*******************************************************************************
 * Function: Terminal_IsRxData
 * Arguments: none
 * Returns status
 * 
 * Created by: R. Merchant
 * Description: Returns true if there is data in the receive register, or false
 *              if not
 ******************************************************************************/
bool Terminal_IsRxData(void)
{
  
    if(U1STAbits.FERR != 0 ){
        U1RXREG; // in case of a framing error, read the data reg to clear err
        return false;
    }
    // Return Rx Data bit from status register
    return U1STAbits.URXDA;
}

/*******************************************************************************
 * Function: _mon_putc
 * Arguments: char c
 * Returns none
 * 
 * Created by: Ed Carryer
 * Description: this is the function that connects the output of printf() to
 *              hardware. In our case, we are going to use it to stuff the
 *              characters into the circular buffer.
 ******************************************************************************/
void _mon_putc (char c)
{
  circular_buf_put(xmitBufferHandle, c);
}

/*******************************************************************************
 * Function: Terminal_MoveBuffer2UART
 * Arguments: none
 * Returns none
 * 
 * Created by: Ed Carryer
 * Description: this functions pulls bytes, if any available, from the
 *              circular buffer and stuffs them into the UART1 buffer
 *              until we either run out of bytes in the circular buffer
 *              or we run out of space in the UART FIFO
 ******************************************************************************/
void Terminal_MoveBuffer2UART( void )
{
  while ( (!circular_buf_empty(xmitBufferHandle)) && (!U1STAbits.UTXBF))
  {
    uint8_t byte2Xmit;
    circular_buf_get(xmitBufferHandle, &byte2Xmit);
    U1TXREG = byte2Xmit;
  }
}
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

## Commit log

2024-10-28 Add code for recording and transcribing on button command
2024-11-07 Add readme and other files
    [DigiKey_mcu.xlsx, DigiKey_microphones.xlsx, ICS-43434.step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]
2024-11-07 Finish readme
    [casing.SLDPRT, casing.STL, casing_back.SLDPRT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]
2024-12-09 Handle case of when asking for goals
2025-05-28 Correct the printing of the response
